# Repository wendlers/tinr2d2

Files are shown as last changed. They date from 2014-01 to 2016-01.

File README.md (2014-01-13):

Simple tin can based, R2D2 like robot using a Parallax Propeller
sw@kaltpost.de
http://gpio.kaltpost.de/

Introduction
------------

Simple tin can based, R2D2 like robot using a Parallax Propeller. While the tin can is used as a body, 
all the parts around the can (bottom base, legs, dome, ...) are 3D printed. 

Usage
-----

The bot software is written in SPIN. Thus, a spin compiler is needed. If unsure how to get the toolchain,
have a look [here](http://gpio.kaltpost.de/?page_id=1378). For the supporting parts, STL and OpenSCAD 
files are provided to use with a 3D printer. 

Images
------

Full Robot, Black

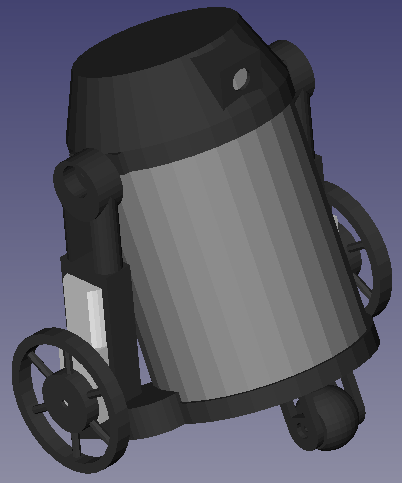
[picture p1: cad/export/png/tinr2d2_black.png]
tinr2d2 black Tin Can R2D2 Black


Full Robot, Pink

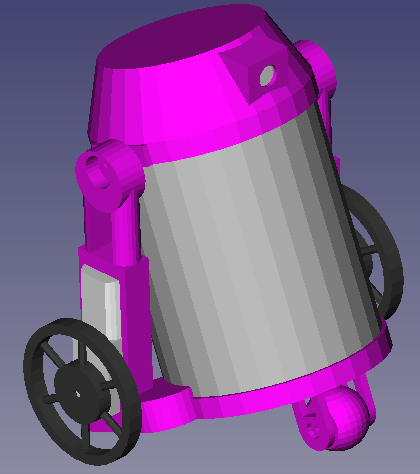
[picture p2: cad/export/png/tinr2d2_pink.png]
tinr2d2 black Tin Can R2D2 pink


Exploded Robot

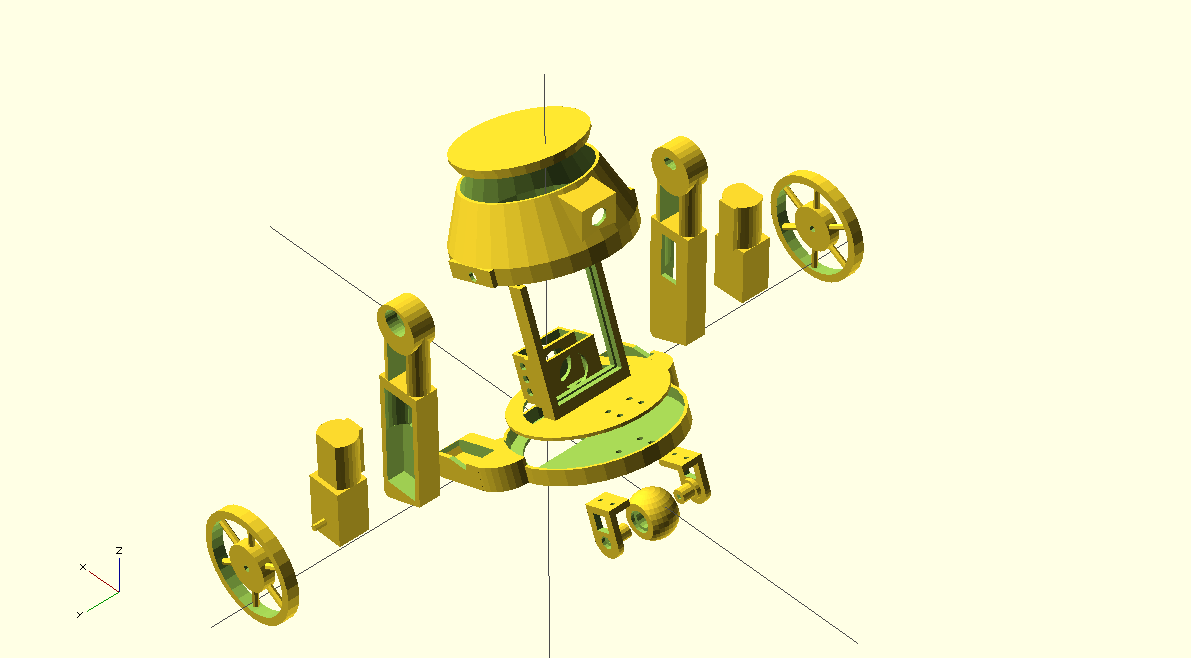
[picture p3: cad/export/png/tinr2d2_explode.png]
tinr2d2 exploded Tin Can R2D2 exploded


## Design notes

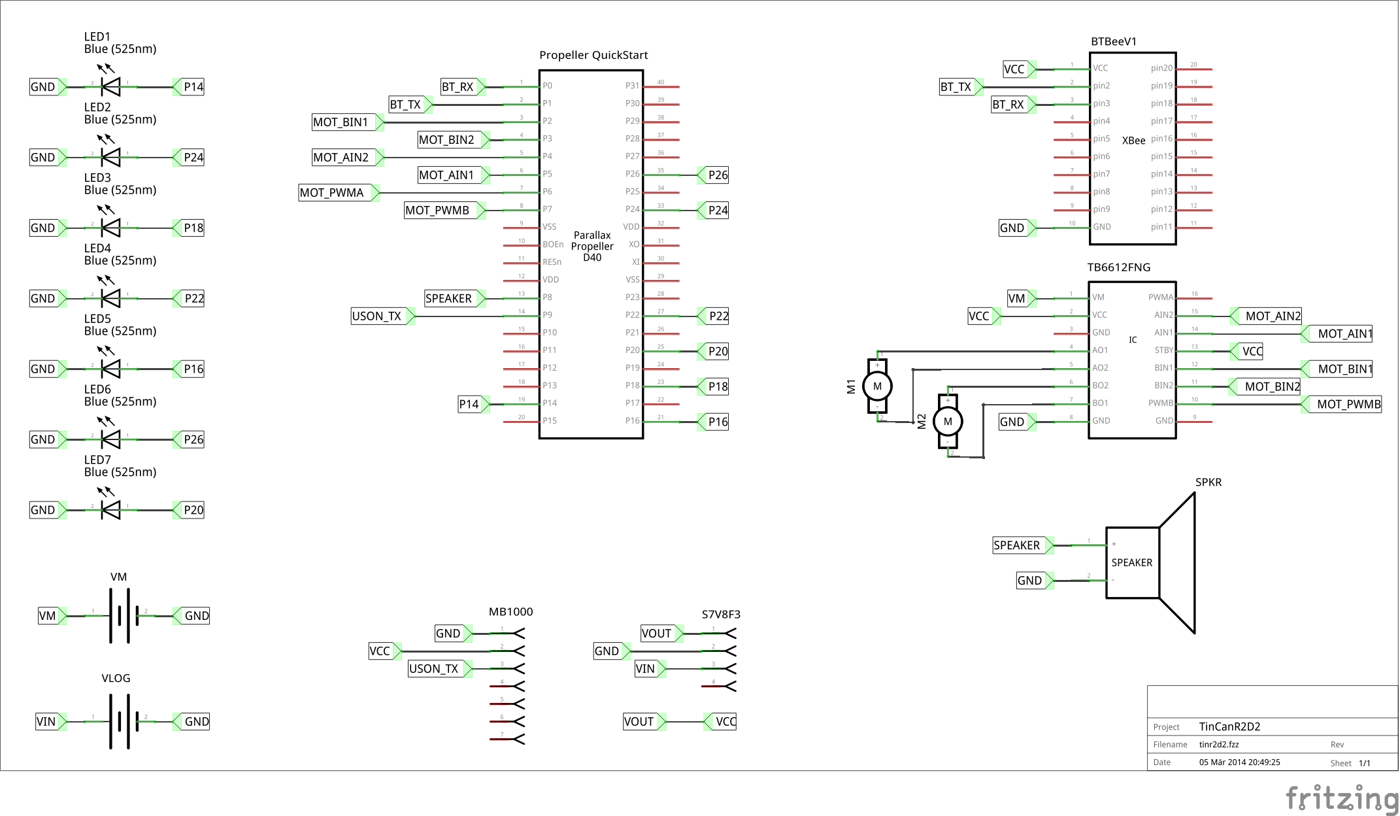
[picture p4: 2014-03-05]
schematic/export/png/tinr2d2_schem.png

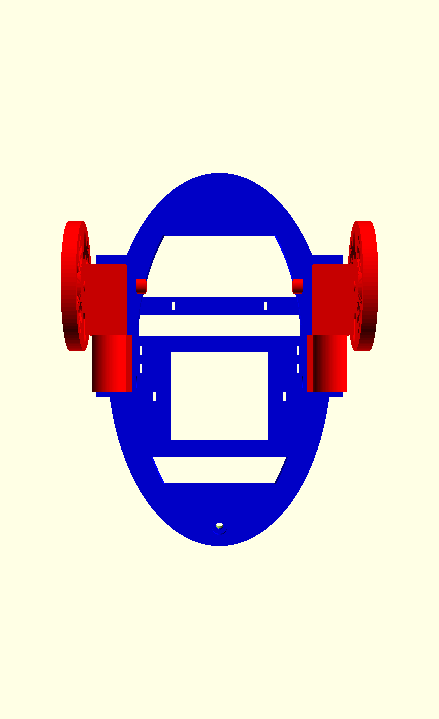
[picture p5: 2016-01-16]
src/pyremote/assets/robot_afwd_bfwd.png

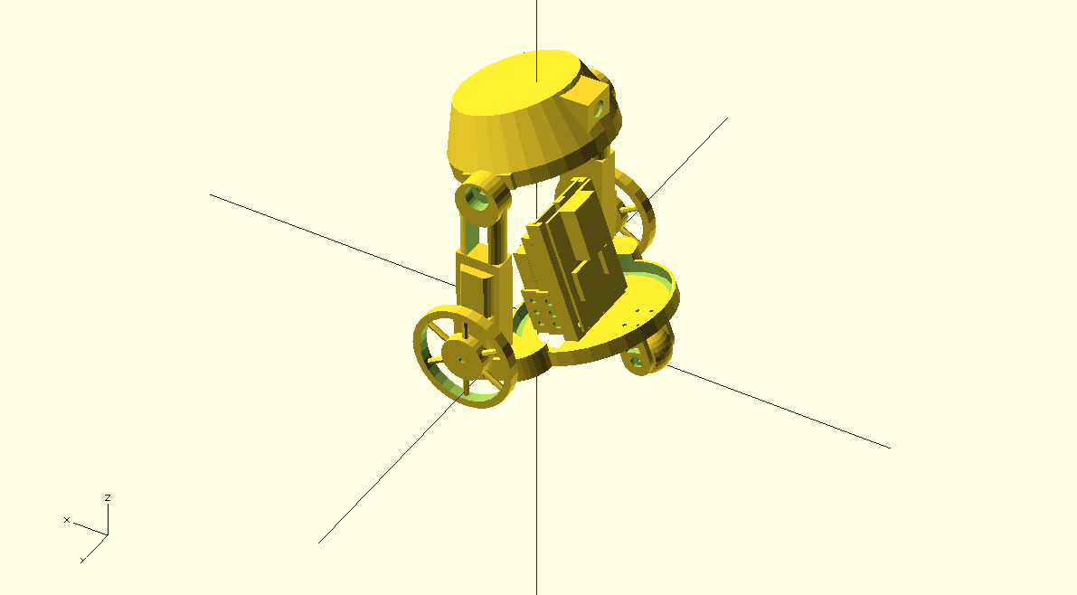
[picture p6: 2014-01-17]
cad/export/png/tinr2d2_skel.png

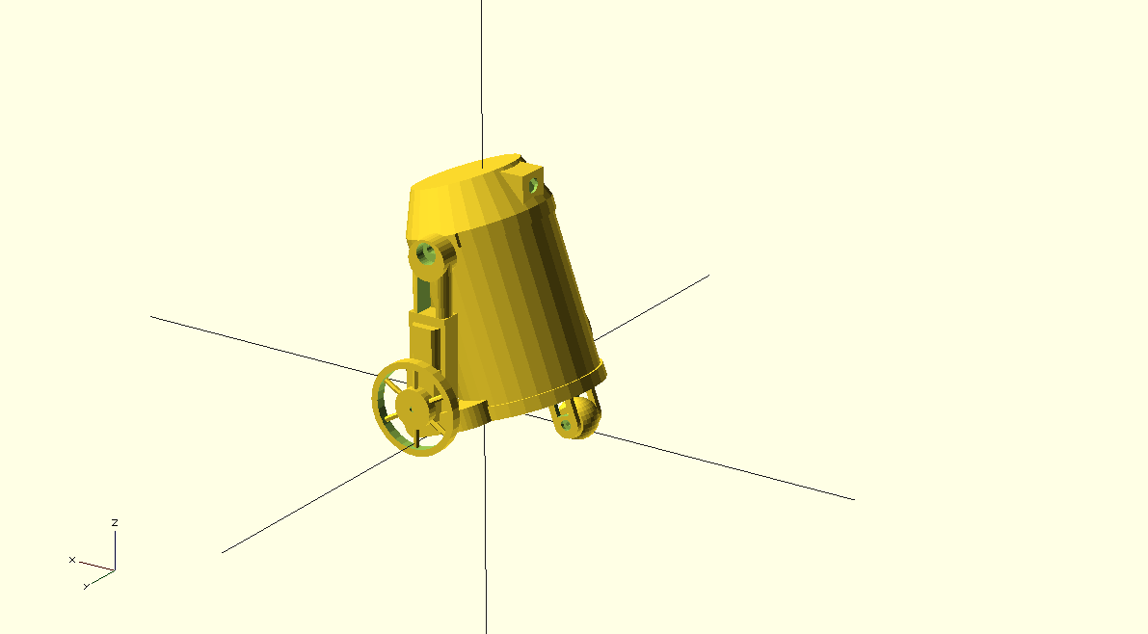
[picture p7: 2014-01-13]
cad/export/png/tinr2d2_full.png

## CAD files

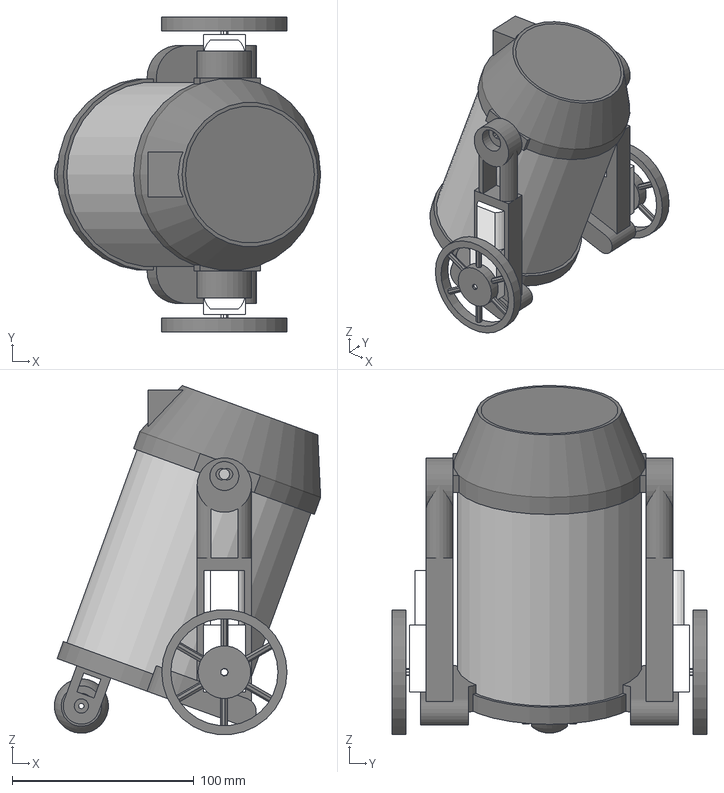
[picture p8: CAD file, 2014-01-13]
cad/export/freecad/tinr2d2_full.fcstd
146.6 x 173.2 x 192.2 mm
bottom_base
top_base
leg1
leg2
front_wheel
dome_top
motor1
motor2
wheel2
wheel1
can

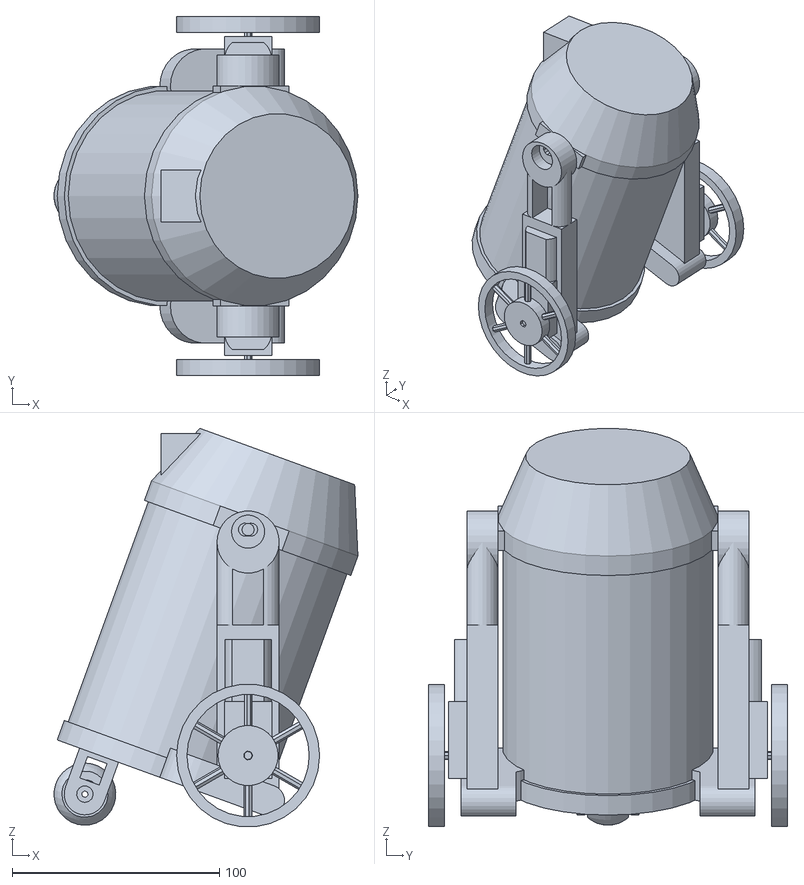
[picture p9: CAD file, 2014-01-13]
cad/export/stl/full.stl
146.6 x 173.2 x 192.2

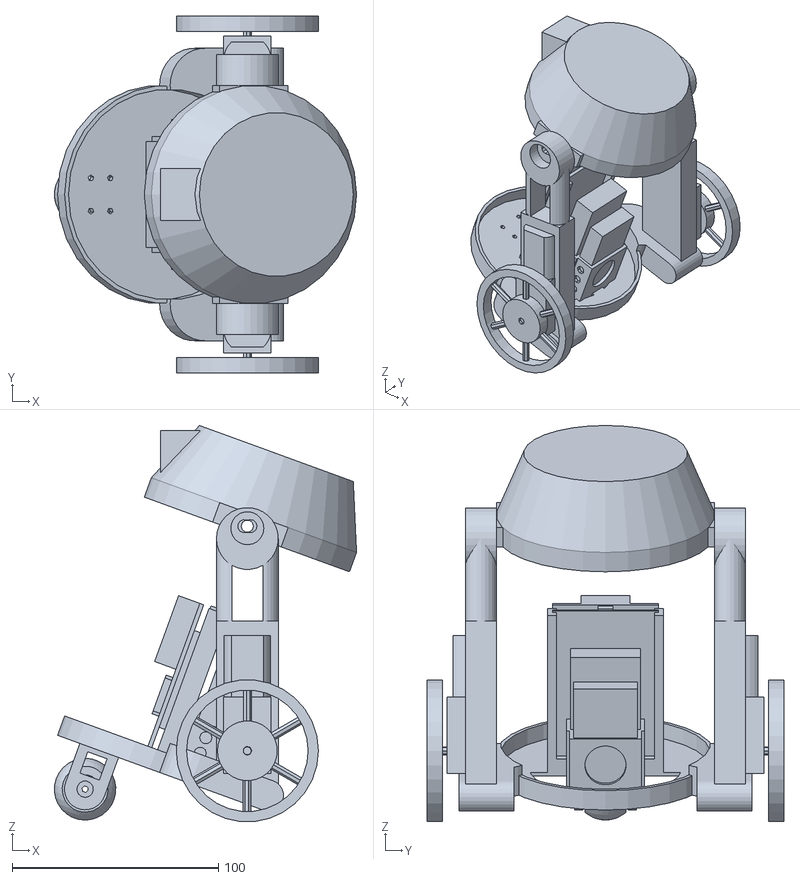
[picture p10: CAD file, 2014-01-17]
cad/export/stl/skel.stl
146.6 x 173.2 x 192.2

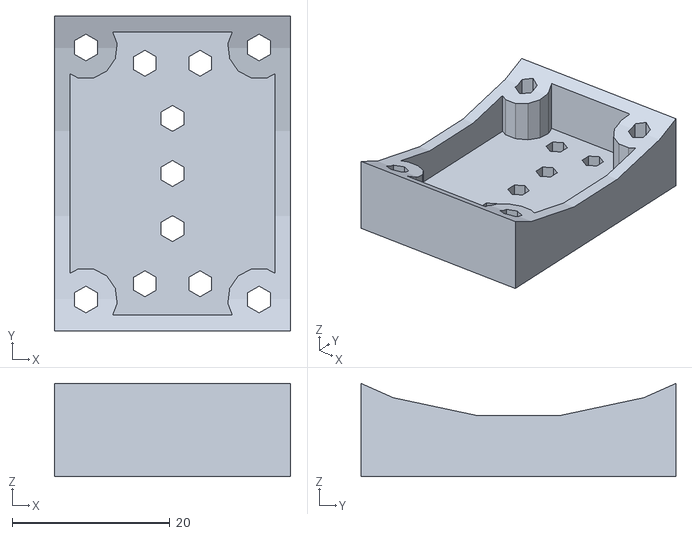
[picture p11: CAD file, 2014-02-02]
cad/print/print_led_panel.stl
30.0 x 40.0 x 11.8

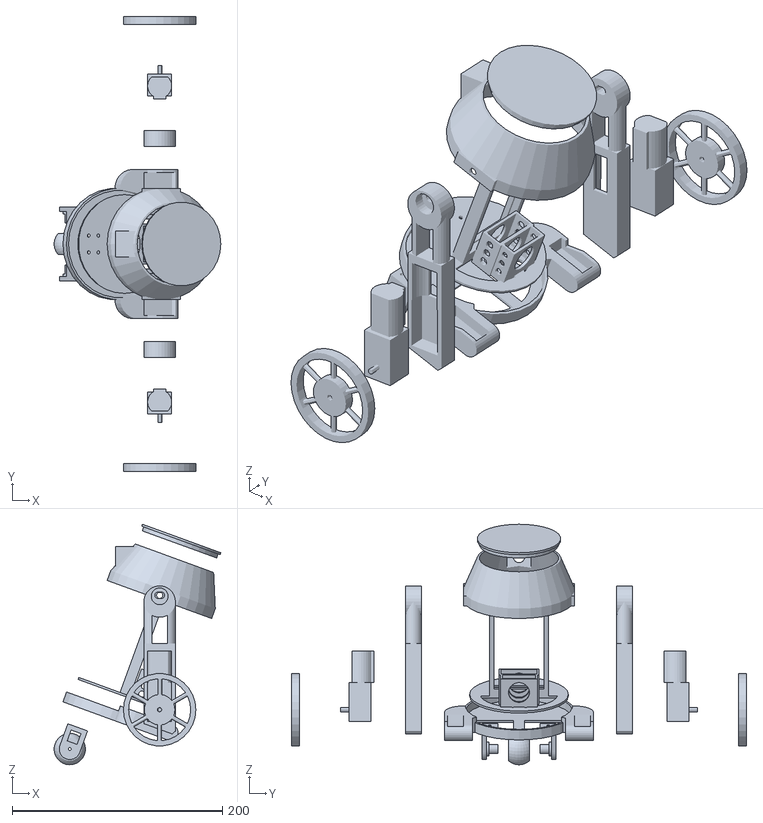
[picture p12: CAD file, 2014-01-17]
cad/export/stl/explode.stl
158.7 x 433.2 x 229.0

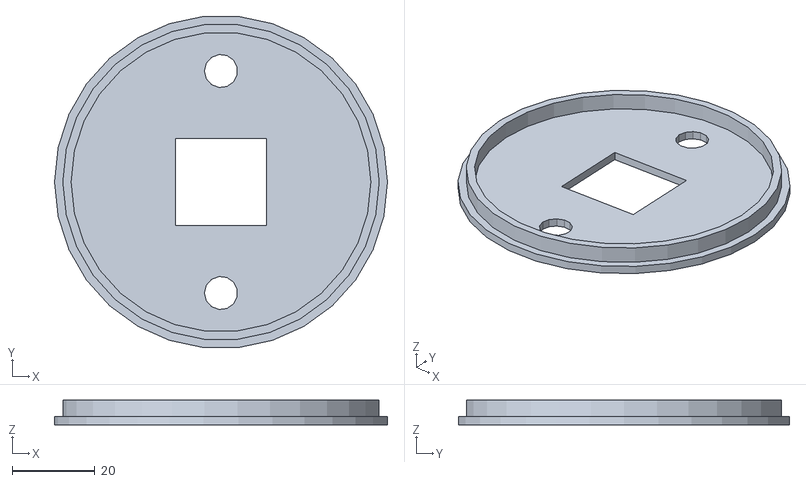
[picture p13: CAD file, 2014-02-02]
cad/print/print_dome_top.stl
80.2 x 79.8 x 6.00

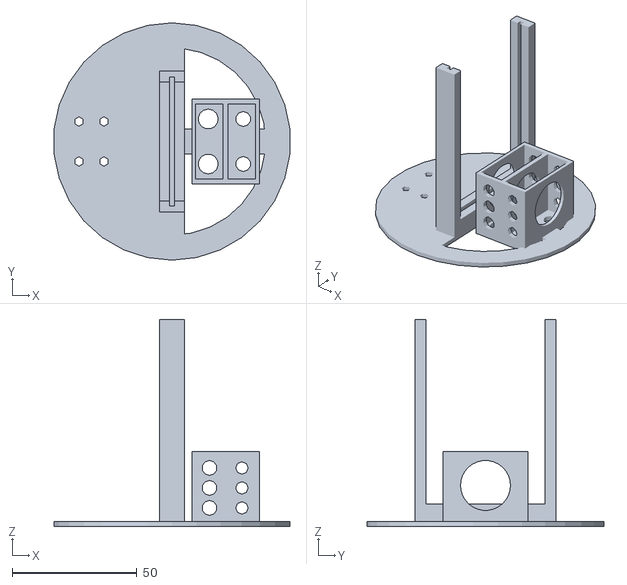
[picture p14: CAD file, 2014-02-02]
cad/print/print_inlay.stl
94.5 x 95.0 x 83.0

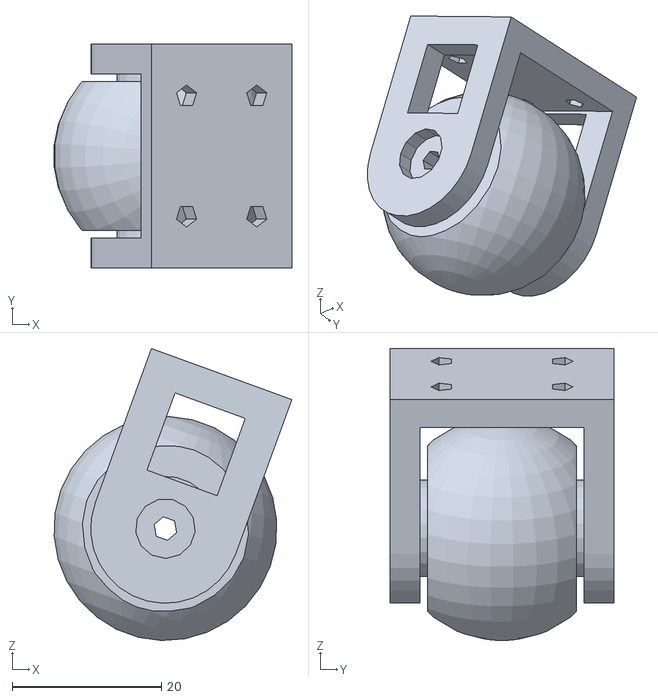
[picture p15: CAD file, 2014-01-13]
cad/export/stl/front_wheel.stl
31.8 x 30.0 x 39.1

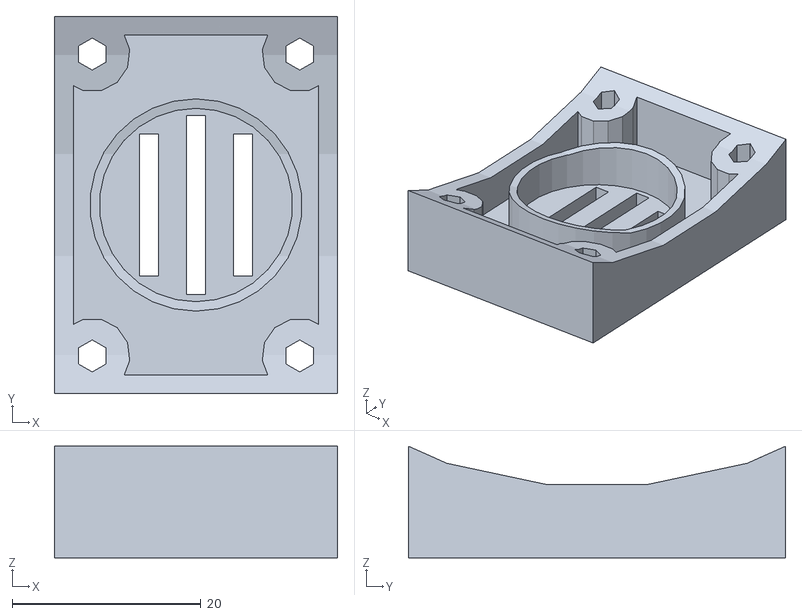
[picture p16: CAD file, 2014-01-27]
cad/print/print_speaker_box.stl
30.0 x 40.0 x 11.8

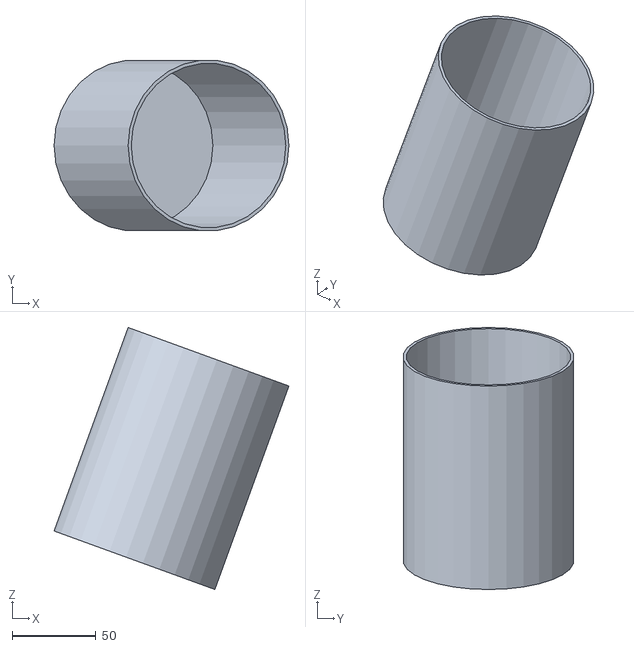
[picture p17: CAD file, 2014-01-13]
cad/export/stl/can.stl
140.0 x 101.4 x 156.1

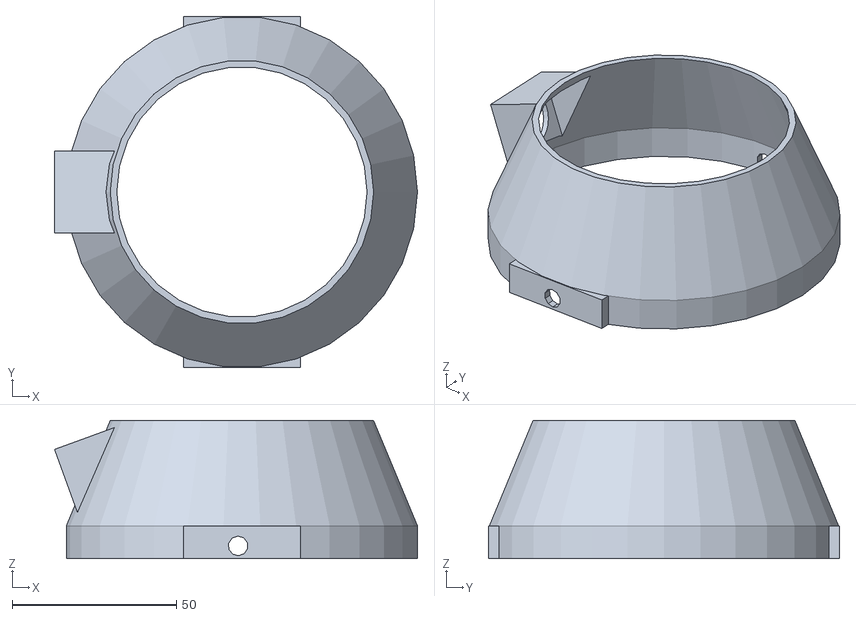
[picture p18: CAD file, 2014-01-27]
cad/print/print_top_base.stl
110.6 x 107.0 x 42.1

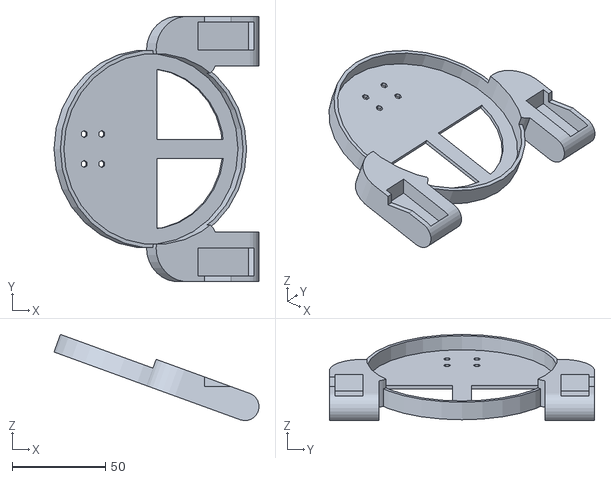
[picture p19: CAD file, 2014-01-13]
cad/export/stl/bottom_base.stl
109.6 x 142.0 x 46.1

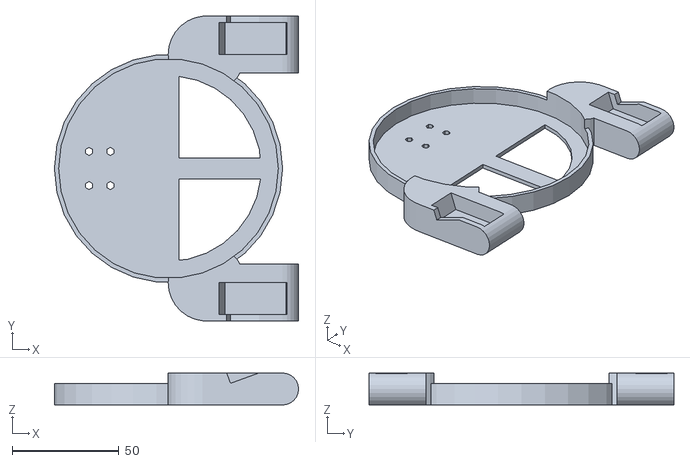
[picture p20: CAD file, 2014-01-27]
cad/print/print_bottom_base.stl
114.5 x 143.0 x 15.0

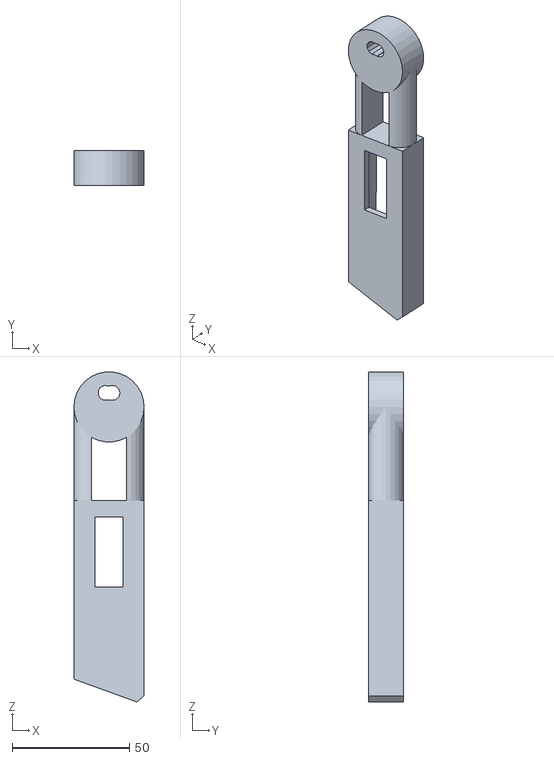
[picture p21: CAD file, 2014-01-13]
cad/export/stl/leg1.stl
30.0 x 15.0 x 140.9

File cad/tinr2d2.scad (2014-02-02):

/**
 * TinCan robot 
 * 
 * 2014-01-05
 * Stefan Wendler
 * sw@kaltpost.de
 */

// ===============================================
// basic params
// ===============================================

can_hig=129;					// hight of tin can
							// 129 is for lavazza espresso can
can_tkn=2;					// thickness of tin can
can_rad=51.5;				// radius of tin can
							// 51.5 is for lavazza espresso can
can_rad_inner=can_rad-4;

base_hig=10;					// hight of top/bottom base
base_tkn=2;					// thickness of top/bottom base borders
base_rad=can_rad+base_tkn;	// radius of top/bottom base

leg_hig=can_hig;				// hight of main legs
leg_tkn=15;					// thickness of main legs
leg_wid=30;					// width of main legs

bod_rot=20;					// deg. of how much can is rotated in respect to the legs


// ===============================================
// what to show
// ===============================================

/* some views showing the robot as a whole */

// show_full_robot(0);
// show_full_robot(1);
// show_exploded_robot();

/* the print views for exporting to STL/3D printer */

// print_front_wheel_ball();
// print_front_wheel_leg1();
// print_front_wheel_leg2();

// print_bottom_base();
// print_top_base();
print_dome_top();

// print_leg1();
// print_leg2();

// print_inlay();
// print_led_panel();
// print_speaker_box();

/* some test views of single parts */

// led_panel();

// speaker_box();

// inlay_base(1);

// inlay(can_hig, 94/2, base_tkn, 1);

// dome(base_rad, 3);
// dome_top(base_rad, 2);

// top_base();
// bottom_base();

// leg(leg_hig, leg_wid, leg_tkn, base_rad, 0);
// leg_drill_hole(leg_hig, leg_wid, leg_tkn, base_rad);

// front_wheel();

// front_wheel_leg(0);

/*
		translate([-can_rad-can_rad*0.5, 0, -40])
			rotate([0, 0, 90])
			{
				front_wheel_ball();
				translate([20, 0, 0])
					front_wheel_leg(0);
				translate([-20, 0, 0])
					mirror([1, 0, 0])
						front_wheel_leg(1);
			}
*/

// translate([-5, 0, 0]) cube([5, 5, 5], center=true);
// translate([ 5, 0, 0]) scale([1.05, 1.05, 1.05]) cube([5, 5, 5], center=true);

/*
	rotate([0, bod_rot, 0])
	{

		translate([-45, 0, 0])
		{
			translate([45, 0, 0])
				bottom_base();

			translate([0, 0, can_hig + 2 * base_tkn]) 
				top_base();
			translate([0, 0, can_hig+base_tkn]) 
			{
				dome_top(base_rad, 2);
			}

				can(can_hig, can_rad, can_tkn);
		}
*/
/*
		translate([-can_rad-can_rad*0.5, 0, -20])
			rotate([0, 0, 90])
				front_wheel();
		}
	}
*/

//	leg(leg_hig, leg_wid, leg_tkn, base_rad, 0);

//	mirror([0, 1, 0]) leg(leg_hig, leg_wid, leg_tkn, base_rad, 0);

// mirror([0, 1, 0])
// mirror([0, 1, 0])
//	translate([-leg_wid/2, base_rad, 0])
//			translate([(leg_wid-23)/2, 24, 15])
//				mirror([0, 1, 0]) wheel();

// ===============================================
// modules
// ===============================================

module can(hig, rad, tkn)
{
	translate([0, 0, tkn]) {
		difference() {
			cylinder(h=hig, r=rad);
			translate([0, 0, tkn]) {
				cylinder(h=hig-tkn, r=rad-tkn);
			}
		}
	}
}

module bottop_cylseg(rad, tkn)
{
	bor=10;		// border to edge of base

	intersection() {	
		translate([bor / 2, bor / 2, 0]) {
			cube([rad-bor, rad-bor, tkn]);
		}
		cylinder(h=tkn, r=rad-bor);
	}
}

module bottop(hig, rad, tkn, halfseg) 
{
	difference() {
		cylinder(h=hig, r=rad);

		if(halfseg != 0)
		{
			translate([0, 0, tkn])
				cylinder(h=hig-tkn, r=rad-tkn);

			bottop_cylseg(rad, tkn);
		}
		else
		{
			cylinder(h=hig, r=rad-tkn);
		}

		if(halfseg != 1 && halfseg != 0)
		{
			rotate([0, 0, 90])
				bottop_cylseg(rad, tkn*2);

			rotate([0, 0, 180])
				bottop_cylseg(rad, tkn*2);
		}	

		if(halfseg != 0)
		{
			rotate([0, 0, 270])
				bottop_cylseg(rad, tkn*2);
		}
	}
}

module wheel()
{
	translate([11.5, -2, 11])
		union() {
			difference() {
				rotate([90, 0, 0])
					cylinder(h=7.6, r=69/2);

				rotate([90, 0, 0])
					cylinder(h=7.6, r=69/2-5);
			}
			difference()
			{

				rotate([90, 0, 0])
					cylinder(h=7.6, r=69/2-20);	

				rotate([90, 0, 0])
					cylinder(h=8, r=2.2);

			}

			difference() {
			for ( i = [0 : 5] )
			{
				rotate([0, 60 * i, 0, 0])
					translate([0, -3, 0])
						cylinder(h=69/2 - 3, r=2);
			}
			rotate([90, 0, 0])
				cylinder(h=8, r=2.2);
			}
		}
}

module motor(show_wheel)
{
	union() {
		cube([23, 21, 37]);
		intersection() {
			translate([11.5, 11.5, 37])
				cylinder(h=30, r=11.5);
	
			translate([0, 3, 37])
				cube([23, 18, 30]);
		}
		translate([11.5-6, 21, 37])
			cube([12, 3, 30]);

		translate([11.5, 0, 11])
			rotate([90, 0, 0])
				cylinder(h=8, r=2);
	}

	if(show_wheel == 1)
	{
		wheel();
	}
	else if(show_wheel == 2)
	{
		translate([0, -45, 0])
			wheel();
	}
}

module bottom(hig, rad, tkn)
{
	union() {
		bottop(hig, rad, tkn, 1);

		difference() {
			translate([rad/3, -rad - 18, 0])	
				cube([rad-rad/3, rad/2, hig+5]);
				// cube([rad-rad/3, 2*rad + 36, hig+5]);
			cylinder(h=hig+5, r=rad - tkn);
		}

		mirror([0,1,0])
			difference() {
				translate([rad/3, -rad - 18, 0])	
					cube([rad-rad/3, rad/2, hig+5]);
					// cube([rad-rad/3, 2*rad + 36, hig+5]);
				cylinder(h=hig+5, r=rad - tkn);
			}

		difference() {	
			translate([rad/3, +rad, 0])
				cylinder(h=hig+5, r=18);
			cylinder(h=hig+5, r=rad - tkn);
		}

		difference() {
			mirror([0, 1, 0])
				translate([rad/3, +rad, 0])
					cylinder(h=hig+5, r=18);
			cylinder(h=hig+5, r=rad - tkn);
		}

		difference() {
			translate([+rad, +rad + 18, (hig+5)/2])
				rotate([90, 0, 0])
					cylinder(h=rad/2, r=(hig+5)/2);
					// cylinder(h=rad*2+36, r=(hig+5)/2);
			cylinder(h=hig + 5, r=rad - tkn);
		}

		mirror([0,1,0])
		difference() {
			translate([+rad, +rad + 18, (hig+5)/2])
				rotate([90, 0, 0])
					cylinder(h=rad/2, r=(hig+5)/2);
					// cylinder(h=rad*2+36, r=(hig+5)/2);
			cylinder(h=hig + 5, r=rad - tkn);
		}

	}
}

module top(hig, rad, tkn, leg_tkn)
{
	shl=base_rad/1.5; 

		union() {
			mirror([0, 0, 1]) bottop(hig, rad, tkn, 0);
	
			difference() {

				translate([-shl/2, rad-base_rad/4, -hig]) 
					cube([shl, base_rad/4, base_hig]);
		
				translate([0, 0, -hig])
					cylinder(h=hig, r=rad-tkn);
			}

			difference() {
				mirror([0, 1, 0])
					translate([-shl/2, rad-base_rad/4, -hig]) 
						cube([shl, base_rad/4, base_hig]);
			
				translate([0, 0, -hig])
					cylinder(h=hig, r=rad-tkn);
			}

			dome(rad , tkn);
		}
}

module battery1()
{
	// battery1_expensive();
	battery1_cheap();
}

module battery2()
{
	// battery2_expensive();
	battery2_cheap();
}

module battery1_expensive()
{
	w=34;
	h=64;
	t=13;

	translate([0, 15, -(76.5-h)/2-4])
		cube([w, t, h], center=true);
}

module battery2_expensive()
{
	w=31;
	h=52;
	t=10;

	translate([0, 28, -(76.5-h)/2-4])
		cube([w, t, h], center=true);
}

// cheap pollin LiPo battery
module battery1_cheap()
{
	w=30;
	h=50;
	t=11;

	translate([0, 15, -(76.5-h)/2-4])
		cube([w, t, h], center=true);
}

// cheap pollin LiPo battery
module battery2_cheap()
{
	w=30;
	h=50;
	t=11;

	translate([0, 28, -(76.5-h)/2-4])
		cube([w, t, h], center=true);
}

module ext_board()
{
	w=51.5;
	h=76.5;
	t=2;

	union()
	{
		// Ext. board
		translate([0, -9, 0])
			cube([w, t, h], center=true);
	
		// BTBee
		translate([0, -9 - 6, h/2 - 34/2])
			cube([24, 12, 34], center=true);

		// Motor controller
		translate([-10, -9 - 2.25, -10])
			cube([20, 4.5, 20], center=true);

		// Step-Up/Down
		translate([+15, -9 - 2.25, -10])
			cube([12, 4.5, 17], center=true);
	}
}

module prop_qs()
{
	w=51.5;
	h=76.5;
	t=2;

	union()
	{
		// Propeller QuickStart board
		cube([w, t, h], center=true);

		// Ext. connector
		translate([w/2-2.5-3, -4, 0])
			cube([5, 8, 50], center=true);

		// USB connector
		translate([0, -2.25, h/2-3.75])
			cube([7.5, 4.5, 9], center=true);
	}
}

module inlay(hig, rad, tkn, showboard)
{
	w1=51.5 + 5;
	w2=51.5 - 4;
	h1=83;
	h2=77;
	t=2;

	union()
	{

		difference()
		{	
			cylinder(h=tkn, r=rad);
/*
			translate([0, 0, -2])
				rotate([0, 0, 180])
					bottop_cylseg(rad, 4*tkn);

			translate([0, 0, -2])
				rotate([0, 0, 270])
					bottop_cylseg(rad, 4*tkn);
*/
			translate([0, 0, -2])
				rotate([0, 0, 90])
					bottop_cylseg(rad, 4*tkn);

			translate([0, 0, -2])
				rotate([0, 0, 0])
					bottop_cylseg(rad, 4*tkn);

		}

		translate([0, 0, h1/2])
		{
			difference()
			{
				cube([w1, 10, h1], center=true);

				translate([0,0,h1-h2])
					cube([w1 - (w1 - w2), 10, h2], center=true);

				translate([0,0,h1-h2-t])
					prop_qs();			
			}

			difference()
			{
				translate([0, 15, -h1/2 + 15])
					cube([34, 14, 30], center=true);
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

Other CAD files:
cad/print/print_front_wheel_leg2.stl
cad/export/stl/wheel1.stl
cad/print/print_leg2.stl
cad/export/stl/dome_top.stl
cad/export/stl/leg2.stl
cad/export/stl/motor1.stl
cad/export/stl/motor2.stl
cad/export/stl/top_base.stl
cad/export/stl/wheel2.stl
cad/print/print_front_wheel.stl
cad/print/print_front_wheel_ball.stl
cad/print/print_front_wheel_leg1.stl
cad/print/print_leg1.stl

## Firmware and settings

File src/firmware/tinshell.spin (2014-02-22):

{{
///////////////////////////////////////////////////////////////////////////////////////////////////////////////////////////////
// TIN CAN BASED R2D - SHELL
//
// Author: Stefan Wendler
// Updated: 2013-11-28
// Designed For: P8X32A
// Version: 1.0
//
// Copyright (c) 2013 Stefan Wendler
// See end of file for terms of use.
//
// Update History:
//
// v1.0 - Initial release       - 2013-11-28
///////////////////////////////////////////////////////////////////////////////////////////////////////////////////////////////

///////////////////////////////////////////////////////////////////////////////////////////////////////////////////////////////
// Circuit Diagram:
//
// TODO
///////////////////////////////////////////////////////////////////////////////////////////////////////////////////////////////

///////////////////////////////////////////////////////////////////////////////////////////////////////////////////////////////
// Brief Description:
//
// M2M Shell which allows to remotely operate a tin can based R2D robot through bulethoot.
///////////////////////////////////////////////////////////////////////////////////////////////////////////////////////////////

///////////////////////////////////////////////////////////////////////////////////////////////////////////////////////////////
// Detailed Description:
//
// The protocol implementatin is as follows:
//
// Drive:
// ======
//
// +d <b|f|l|r|s>
// - b : backward
// - f : foreward
// - l : turn left
// - r : turn right
// - s : stop (break)
//
// On success, noting is returned.
// On error, an error message of the form:
//
// !ERR <err-nr:1..2>
//
// is returned.
//
// Example 1: drive foreward:
//
// +d f
// <nothing returned>
//
// Example 2: stop:
//
// +d s
// <nothing returned>
//
// Example 3: invalid command:
//
// +d x
// !ERR 2
//
//
// Increase/decrease Motor Speed:
// ==============================
//
// +s <a|b> <+|->
// - a : adjust speed for motor A
// - b : adjust speed for motor
// - + : increase speed for selected motor
// - - : decrease speed for selected motor
//
//
// On success, noting is returned.
// On error, an error message of the form:
//
// !ERR <err-nr:1..4>
//
// is returned.
//
// Example 1: increase speed of motor A:
//
// +s a +
// <nothing returned>
//
// Example 2: decrease speed of motor B:
//
// +s b -
// <nothing returned>
//
// Example 3: invalid motor:
//
// +s c +
// !ERR 2
///////////////////////////////////////////////////////////////////////////////////////////////////////////////////////////////
}}

CON

  '' Clock settings
  '' _clkmode = rcfast                                  ' Internal clock at 12MHz

  _CLKMODE = XTAL1 + PLL16X                             ' External clock at 80MHz
  _XINFREQ = 5_000_000

  BAUD_RATE_V1     = 9_600

  RX_PIN_V1 	   = 1
  TX_PIN_V1 	   = 0

  MOT_AO1_V1       = 3
  MOT_AO2_V1       = 2
  MOT_PWMA_V1      = 6
  MOT_BO1_V1       = 5
  MOT_BO2_V1       = 4
  MOT_PWMB_V1      = 7

  SPEAKER_V1       = 8
  MB1000_V1        = 9

  LED1_V1          = 16
  LED2_V1          = 26
  LED3_V1          = 18
  LED4_V1          = 20
  LED5_V1          = 24
  LED6_V1          = 22
  LED7_V1          = 14

  BAUD_RATE_V2     = 115_200

  RX_PIN_V2 	   = 1
  TX_PIN_V2 	   = 0

  MOT_AO1_V2       = 5
  MOT_AO2_V2       = 4
  MOT_PWMA_V2      = 6
  MOT_BO1_V2       = 2
  MOT_BO2_V2       = 3
  MOT_PWMB_V2      = 7

  SPEAKER_V2       = 8
  MB1000_V2        = 9

  LED1_V2          = 14
  LED2_V2          = 24
  LED3_V2          = 18
  LED4_V2          = 22
  LED5_V2          = 16
  LED6_V2          = 26
  LED7_V2          = 20

OBJ

  ps	: "propshell"
  dp    : "drivepilot"
  se    : "soundeffects"
  le    : "lighteffects"

VAR

  '' None

PUB main | i

'' ////////////////////////////////////////////////////////////////////////////////////////////////////////////////////////////
'' // Main routine. Init the shell, prompt for commands, handle commands.
'' ////////////////////////////////////////////////////////////////////////////////////////////////////////////////////////////

  '' initV1
  initV2

  dp.scheduleAction(dp#DRIVE_ST)

  repeat

    result := ps.prompt

    \cmdHandler(result)

PRI initV1

  le.start(LED1_V1, LED2_V1, LED3_V1, LED4_V1, LED5_V1, LED6_V1, LED7_V1)
  se.start(SPEAKER_V1)
  dp.start(MOT_AO1_V1, MOT_AO2_V1, MOT_PWMA_V1, MOT_BO1_V1, MOT_BO2_V1, MOT_PWMB_V1, MB1000_V1)

  le.scheduleEffect(le#POWERUP)
  se.scheduleEffect(se#BEEP1)

  ps.init(false, false, BAUD_RATE_V1, RX_PIN_V1, TX_PIN_V1)
  ps.puts(string("!INFO tinshell ready", ps#CR, ps#LF))

PRI initV2

  le.start(LED1_V2, LED2_V2, LED3_V2, LED4_V2, LED5_V2, LED6_V2, LED7_V2)
  se.start(SPEAKER_V2)
  dp.start(MOT_AO1_V2, MOT_AO2_V2, MOT_PWMA_V2, MOT_BO1_V2, MOT_BO2_V2, MOT_PWMB_V2, MB1000_V2)

  le.scheduleEffect(le#POWERUP)
  se.scheduleEffect(se#BEEP1)

  ps.init(false, false, BAUD_RATE_V2, RX_PIN_V2, TX_PIN_V2)
  ps.puts(string("!INFO tinshell ready", ps#CR, ps#LF))

PRI cmdHandler(cmdLine)
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

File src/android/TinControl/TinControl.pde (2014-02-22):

/* 
 * This file is part of the TinCan R2D2 project
 *
 * Copyright (C) 2014 Stefan Wendler <sw@kaltpost.de>
 *
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
 * You should have received a copy of the GNU Lesser General Public
 * License along with the JRocket firmware; if not, write to the Free
 * Software Foundation, Inc., 59 Temple Place, Suite 330, Boston, MA
 * 02111-1307 USA.  
 */

import android.content.Intent;
import android.os.Bundle;
import android.view.KeyEvent;

import ketai.net.bluetooth.*;
import ketai.ui.*;
import ketai.net.*;

KetaiBluetooth bt;
KetaiList klist;

Gui g;

TextBox discMsg;

byte cnt1 = 0;
byte cnt2 = 0;
  
void setup()
{
  //size(1280, 768);
  size(displayWidth, displayHeight);
  frameRate(15);
  orientation(LANDSCAPE);
 
  g = new Gui(this, displayWidth, displayHeight);
  
  println("W=" + displayWidth + ", H=" + displayHeight);
  
  //start listening for BT connections
  bt.start();
 
  background(0);
  discMsg = new TextBox("Discovering ...", 10, 10, displayWidth - 20, displayHeight - 20);
 
  bt.discoverDevices();
}

void draw()
{  
  if(!g.isVisible())
  {  
    if(bt.isDiscovering())
    {
      if(cnt1++ == 10)
      {
        cnt2++;
        if(cnt2 > 2)
        {
          cnt2 = 0;
        }
        cnt1 = 0;
      }
      
      int f1 = 0; 
      int f2 = 0;
      int f3 = 0;

      if(cnt2 == 0)
      {
        f1 = 128;
      }
      else if(cnt2 == 1)
      {
        f2 = 128;
      }
      else if(cnt2 == 2)
      {
        f3 = 128;
      }
      
      discMsg.draw();
            
      fill(f1);
      ellipse(displayWidth / 2 - 30, displayHeight / 2 + 60, 20, 20);
      fill(f2);
      ellipse(displayWidth / 2, displayHeight / 2 + 60, 20, 20);
      fill(f3);
      ellipse(displayWidth / 2 + 30, displayHeight / 2 + 60, 20, 20);
    }
    else
    {
      klist = new KetaiList(this, bt.getDiscoveredDeviceNames());
      
      background(0);
      g.setVisible(true);
    }
  }
}

void onKetaiListSelection(KetaiList klist)
{  
  String selection = klist.getSelection();
  
  String name = selection;
  String addr = bt.lookupAddressByName(selection);

  // if canceled, discover again ...
  if(name == "")
  {
     println("Canceled ..");
     klist = null;
     g.setVisible(false);
     bt.discoverDevices();
     return;
  }
  
  println("Connecting to: " + name + " (" + addr + ")");
  bt.connectDevice(addr);
  
  try
  {
    Thread.sleep(750);
  }
  catch(Exception e)
  {
  }
   
  g.registerBt(bt);

  //dispose of list for now
  klist = null;
}

//Call back method to manage data received
void onBluetoothDataEvent(String who, byte[] data)
{
  if(!g.isVisible())
    return;
    
  String s = new String(data);
  
  println("Received " + data.length +  " bytes : " + s);
  
  g.setMsg(s);
}

boolean surfaceKeyDown(int code, KeyEvent event) 
{
  if(event.getKeyCode() == KeyEvent.KEYCODE_BACK) 
  {
    if(g.isVisible())
    {      
      // back to selection
      g.setVisible(false);
      
      // restart bt to disconnect existing connections
      bt.stop();
      bt.start();
      
      bt.discoverDevices();
      return true;
    }
  }
  
  // else default key behavior is used
  return super.surfaceKeyDown(code, event);
}
//********************************************************************
// The following code is required to enable bluetooth at startup.
//********************************************************************
void onCreate(Bundle savedInstanceState) {
  super.onCreate(savedInstanceState);
  bt = new KetaiBluetooth(this);
}

void onActivityResult(int requestCode, int resultCode, Intent data) {
  bt.onActivityResult(requestCode, resultCode, data);
}

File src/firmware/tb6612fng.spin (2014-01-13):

{{
///////////////////////////////////////////////////////////////////////////////////////////////////////////////////////////////
// TB6612FNG MOTOR DRIVER
//
//
// Author: Stefan Wendler
// Updated: 2013-11-28
// Designed For: P8X32A
// Version: 1.0
//
// Copyright (c) 2013 Stefan Wendler
// See end of file for terms of use.
//
// Update History:
//
// v1.0 - Initial release       - 2013-11-28
///////////////////////////////////////////////////////////////////////////////////////////////////////////////////////////////

///////////////////////////////////////////////////////////////////////////////////////////////////////////////////////////////
// Circuit Diagram:
//
// PIN AO1       --- AO1,  Motor A out 1
// PIN AO2       --- AO2,  Motor A out 2
// PIN PWMA      --- PWMA, Motor A PWM (for speed control)
// PIN BO1       --- BO1,  Motor B out 1
// PIN BO2       --- BO2,  Motor B out 2
// PIN PWMB      --- PWMB, Motor B PWM (for speed control)
///////////////////////////////////////////////////////////////////////////////////////////////////////////////////////////////

///////////////////////////////////////////////////////////////////////////////////////////////////////////////////////////////
// Brief Description:
//
// Dirve two motors through the TB6612FNG dual motor dirver. Allows (optional) to adjust the speed for each motor in %.
// Speed adjustment is done through the TB6612FNG PWM input. For motor (A or B) PWM is used, a Cog is reserved to generate
// the PWM. The driver offers methods to operate each motor individually or both motors together (by sending the same command
// to each, or sending a different command to each).
///////////////////////////////////////////////////////////////////////////////////////////////////////////////////////////////

///////////////////////////////////////////////////////////////////////////////////////////////////////////////////////////////
// Detailed Description:
//
// For detailed usage, see the example.
///////////////////////////////////////////////////////////////////////////////////////////////////////////////////////////////
}}

CON

  PWM_FREQ_HZ   = 18_000        ' Freq. for PWM
  INITIAL_DC_PC = 100           ' Initial duty-cycle for PWM

  MOT_A       = 1               ' Address motor A
  MOT_B       = 2               ' Address motor B

  CMD_CW      = 1               ' Drive motor clock wise
  CMD_CCW     = 2               ' Drive motor counter clock wise
  CMD_STOP    = 3               ' Stop (break) motor

VAR

  byte pinAO1
  byte pinAO2
  byte pinBO1
  byte pinBO2

OBJ

  pwma	: "pwm"
  pwmb	: "pwm"

PUB init(aPinAO1, aPinAO2, aPinPWMA, aPinBO1, aPinBO2, aPinPWMB)

'' ////////////////////////////////////////////////////////////////////////////////////////////////////////////////////////////
'' // Initialize the TB6612FNG motor driver
'' //
'' // @param                    aPinAO1                 Motor A output pin for motor operation 1
'' // @param                    aPinAO2                 Motor A output pin for motor operation 2
'' // @param                    aPinPWMA                Motor A output pin for motor PWM, or false if NC
'' // @param                    aPinBO1                 Motor B output pin for motor operation 1
'' // @param                    aPinBO2                 Motor B output pin for motor operation 2
'' // @param                    aPinPWMB                Motor B output pin for motor PWM, or false if NC
'' ////////////////////////////////////////////////////////////////////////////////////////////////////////////////////////////

  pinAO1 := aPinAO1
  pinAO2 := aPinAO2
  pinBO1 := aPinBO1
  pinBO2 := aPinBO2

  if aPinPWMA
    pwma.start(aPinPWMA, PWM_FREQ_HZ, INITIAL_DC_PC)

  if aPinPWMB
    pwmb.start(aPinPWMB, PWM_FREQ_HZ, INITIAL_DC_PC)

  dira[pinAO1] := 1
  dira[pinAO2] := 1
  dira[pinBO1] := 1
  dira[pinBO2] := 1

  operateSync(CMD_STOP)

PUB operate(motor, command) | o1, o2, f1, f2

'' ////////////////////////////////////////////////////////////////////////////////////////////////////////////////////////////
'' // Operate a single motor (MOT_A or MOT_B)
'' //
'' // @param                    motor                   Motor to operate (MOT_A or MOT_B)
'' // @param                    command                 Command to send (CMD_CW, CMD_CCW or CMD_STOP)
'' ////////////////////////////////////////////////////////////////////////////////////////////////////////////////////////////

  if motor == MOT_A
    o1 := pinAO1
    o2 := pinAO2
  else
    o1 := pinBO1
    o2 := pinBO2

  if command == CMD_CW
    f1 := 0
    f2 := 1
  elseif command == CMD_CCW
    f1 := 1
    f2 := 0
  else
    f1 := 1
    f2 := 1

  outa[o1] := f1
  outa[o2] := f2

PUB operateAsync(commandA, commandB)
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

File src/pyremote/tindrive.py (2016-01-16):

from tinr2d2 import TinR2D2
import pygame

__author__ = 'stefan'


def robot_ctrl():

    robot_prev_state = None
    robot = TinR2D2("/dev/rfcomm3")

    robot_images = {
        robot.stop: pygame.image.load("assets/robot_aoff_boff.png"),
        robot.forward: pygame.image.load("assets/robot_afwd_bfwd.png"),
        robot.backward: pygame.image.load("assets/robot_abwd_bbwd.png"),
        robot.left: pygame.image.load("assets/robot_abwd_bfwd.png"),
        robot.right: pygame.image.load("assets/robot_afwd_bbwd.png")
    }

    robot_image_rect = robot_images[robot.stop].get_rect()
    robot_image_rect.left = 0

    pygame.init()

    size = [robot_image_rect.width, robot_image_rect.height]
    screen = pygame.display.set_mode(size)

    pygame.display.set_caption("Tin Drive")

    done = False
    clock = pygame.time.Clock()

    pygame.joystick.init()
    joystick_count = pygame.joystick.get_count()

    assert joystick_count > 0, "No Joystick found!"

    joystick = pygame.joystick.Joystick(0)
    joystick.init()

    assert joystick.get_name() in ["Sony PLAYSTATION(R)3 Controller", "Microsoft X-Box 360 pad"], \
        "Joystick 0 is not a PS3 or X-Box 360 controller (found '%s')" % joystick.get_name()

    is_ps3 = joystick.get_name() == "Sony PLAYSTATION(R)3 Controller"

    while not done:

        for event in pygame.event.get():
            if event.type == pygame.QUIT:
                done = True

        if is_ps3:

            button_up = joystick.get_button(4)
            button_down = joystick.get_button(6)
            button_left = joystick.get_button(7)
            button_right = joystick.get_button(5)

        else:

            hat_x, hat_y = joystick.get_hat(0)

            button_up = (hat_y == 1)
            button_down = (hat_y == -1)
            button_left = (hat_x == -1)
            button_right = (hat_x == 1)

        if button_up:
            robot_state = robot.forward
        elif button_down:
            robot_state = robot.backward
        elif button_left:
            robot_state = robot.left
        elif button_right:
            robot_state = robot.right
        else:
            robot_state = robot.stop

        if robot_state != robot_prev_state:
            robot_state()
            robot_prev_state = robot_state

        screen.blit(robot_images[robot_state], robot_image_rect)

        pygame.display.flip()
        clock.tick(20)

try:
    robot_ctrl()
except Exception as e:
    print(e)

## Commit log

2014-01-13 Added some full views
    [explode.stl, full.stl, skel.stl]
2014-01-15 added inlay to hold electronics and batteries
    [explode.stl, print_dome_top.stl, print_inlay.stl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]
2014-01-17 reworked inlay
    [explode.stl, print_inlay.stl, skel.stl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]
2014-01-19 changed baudrate für BTBee to 9600
    [print_inlay.stl, tinr2d2.scad]
2014-01-19 add hole for switch to dome top, added LED panel to sit on front of can
    [print_dome_top.stl, print_led_panel.stl, tinr2d2.scad]
2014-01-22 added LED panel
    [tinr2d2.scad]
2014-01-27 Added 3D part for speaker box, added effect objects for sound and light, added object to read from MB1000 ultrasonic sensor
    [print_bottom_base.stl, print_front_wheel.stl, print_front_wheel_leg2.stl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]
2014-02-02 minor reworks
    [print_dome_top.stl, print_inlay.stl, print_led_panel.stl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]
2014-03-05 Added schematic ...
    [tinr2d2.fzz]

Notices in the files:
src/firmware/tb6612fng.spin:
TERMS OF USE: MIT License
